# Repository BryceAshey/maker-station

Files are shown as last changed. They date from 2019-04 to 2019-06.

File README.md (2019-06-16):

# Maker Station
Powering your maker prototypes + some extra fun with HUE

Maker Station

## Setup

### Setup python and i2c on the pi
		sudo apt-get update
		
		sudo apt-get install python3 python3-pip git
		
		sudo pip3 install smbus2
		
		sudo apt-get install -y i2c-tools

### Setup hue
Install the phue lib

		sudo pip3 install phue

Set an environ var of HUE_BRIDGE_IP to the IP of your hue bridge

Set an environ var of HUE_BRIDGE_USERNAME to an authorized username from your Hue. 

To get a username from your hue: https://www.sitebase.be/generate-phillips-hue-api-token/

### Setup megaio
This will setup megaio from the command line and for use by python

		~$ git clone https://github.com/SequentMicrosystems/megaio-rpi.git
		
		~$ cd megaio-rpi/
		
		~/megaio-rpi$ sudo make install

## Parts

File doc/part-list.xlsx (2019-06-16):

Vendor | Part No. | Manufacturer | Description | Quantity | Cost Ea. | Cost Total
digikey.com | ECE60US05-S | XP Power | 10amp of 5v Power | 1 | $87.55 | $87.55
digikey.com | ECE60US12-S | XP Power | 10amp of 12v Power | 1 | $87.55 | $87.55
adafruit.com | 3055 | Raspberry Pi | Raspberry Pi 3 - Model B - ARMv8 with 1G RAM | 1 | $35.00 | $35.00
adafruit.com | 3708 | Raspberry Pi | Raspberry Pi Zero WH (Zero W with Headers) | 1 | $14.00 | $14.00
adafruit.com | 2883 | Raspberry Pi | Adafruit Pi Protector for Raspberry Pi Model Zero | 1 | $4.95 | $4.95
amazon.com | B014KTSMLA | Sunfounder | SunFounder PCA9685 16 Channel 12 Bit PWM Servo Driver for Arduino and Raspberry Pi | 1 | $10.19 | $10.19
robotshop.com | RB-SQM-02 | Sequent Microsystems | Mega-IO Expansion Card for Raspberry Pi/Zero | 1 | $35.00 | $35.00
sparkfun.com | bob-12700 | SparkFun | SparkFun USB Type A Female Breakout | 9 | $4.50 | $40.50
amazon.com | LA128A | Baomain | push button switch 16mm Momentary 1NO 1NC 3V White Neon Light rectangle 5 Pack | 3 | $7.19 | $21.57
sparkfun.com | COM-11310 | SparkFun | Toggle Switch and Cover - Illuminated (Red) | 2 | $2.95 | $5.90
adafruit.com | 3174 | adafruit | Hook-up Wire Spool Set - 22AWG Solid Core - 10 x 25ft | 1 | $29.95 | $29.95
grainger.com | 5ZDG7 | grainger | 100' 18ga red hookup wire (only need 30' ish) | 1 | $28.27 | $28.27
grainger.com | 5ZDG5 | grainger | 100' 18ga black hookup wire (only need 30' ish) | 1 | $28.27 | $28.27
dynamism.com | Ultimaker NFC PLA - Red | ultimaker | Ultimaker NFC PLA - Red Filament, .75kg, 2.85mm | 2 | $49.95 | $99.90
amazon.com | 260-004-BR | E-Z LOK | EZ Lok 260-004-BR, 4-40 Flanged Press Insert, Brass - Lot of 50 | 2 | $17.00 | $34.00
grainger.com | 4XB86 | FABORY | #4-40 x 1/4", Cylindrical, Socket Head Cap Screw, Alloy Steel, Steel, Black Oxide Finish, 100PK | 1 | $11.64 | $11.64
microfasteners.com | fwk04 | micro | #4 - Flat Washers - Black Oxide 100 pcs/pkg | 1 | $2.00 | $2.00
 |  |  | USB mount screws - unknown! | 8 |  | $0.00
 |  |  | USB mount screw nuts - unknown! | 24 |  | $0.00
 |  |  | Numerous JST Connectors
 |  |  | Total Cost at Build: |  |  | $576.24

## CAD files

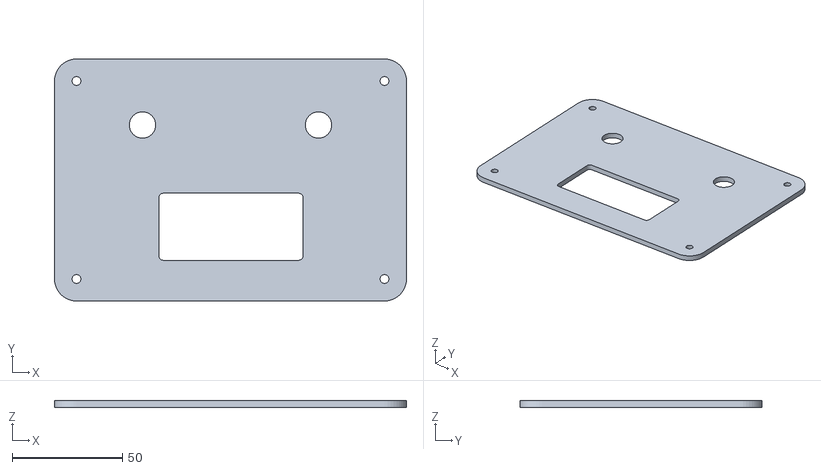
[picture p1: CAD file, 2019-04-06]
doc/stl/PowerBoxFacePlateWPiZero.stl
160.0 x 110.0 x 3.00

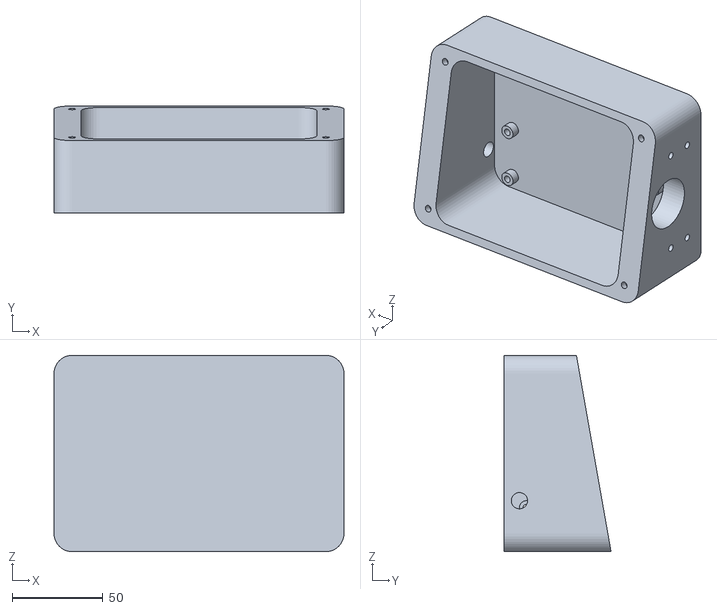
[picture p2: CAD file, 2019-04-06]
doc/stl/PowerBoxRight.stl
160.0 x 59.1 x 108.3

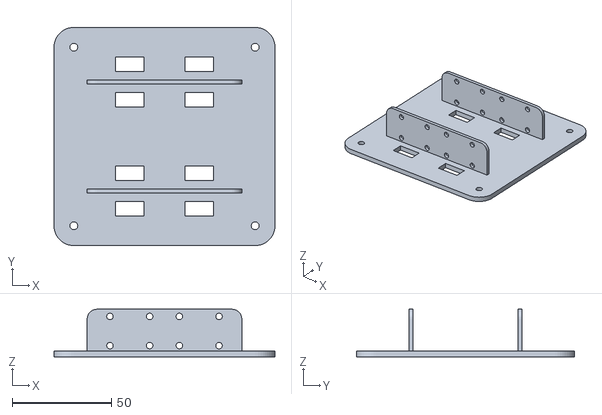
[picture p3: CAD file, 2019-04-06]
doc/stl/SmallBoxUsbPlate.stl
111.4 x 110.0 x 24.0

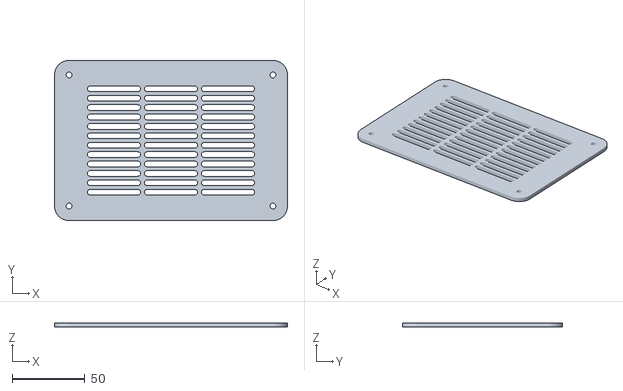
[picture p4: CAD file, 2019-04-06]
doc/stl/LargeBoxVentFaceplate.stl
160.0 x 110.0 x 3.00

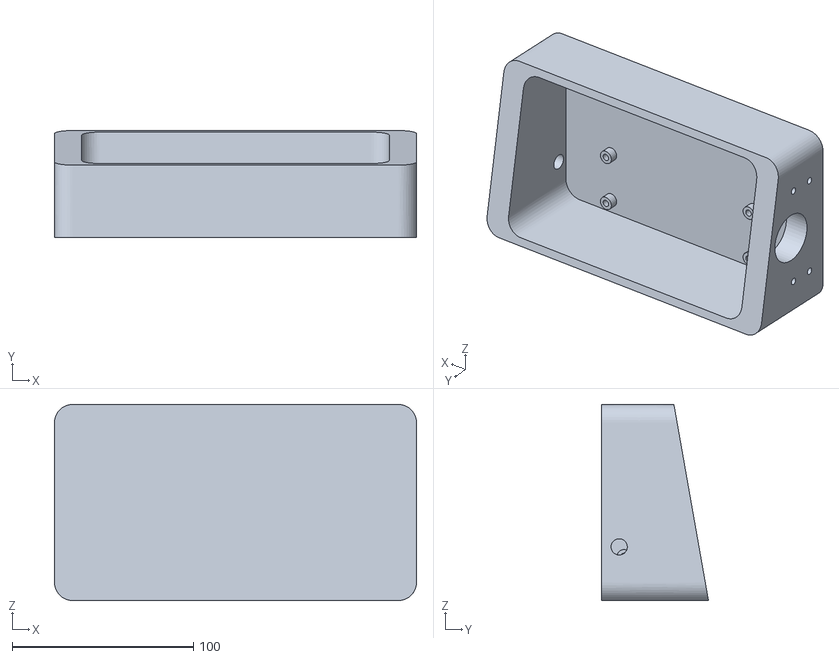
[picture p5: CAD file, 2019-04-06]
doc/stl/PowerBox.stl
200.0 x 59.1 x 108.3

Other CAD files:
doc/stl/ComputeBox.stl
doc/stl/Maker Station v39.f3d

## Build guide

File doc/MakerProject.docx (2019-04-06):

As makers we deal with the common problem of powering our creations while we’re prototyping them. For me, it’s not an uncommon occurrence to have a couple Raspberry Pi’s, an Arduino, and maybe a 7” touchscreen or two sitting on the workbench at any given point in time. When I originally came up with the concept for the Maker Station I was searching for a solution to that power problem and, ideally, I wanted a project that would force me to learn CAD, wiring with JST connectors, to develop a better understanding of the Raspberry’s GPIO and the I2C protocol, and whatever other geekery I could pile into the project. After a solid four weeks of development I can safely say Maker Station met all those desires and then some.

Specifications:

Power: 10 amps @5v via 8 USB

Switching capability: 15

Compute: Raspberry Pi Model 3b (although the 2 through 3b+ would work fine) – make sure you have Wi-Fi ability

PCA9685 I2C Controller (used for the switch LEDs not servos)

A spare Pi-Zero is installed on the power box faceplate but not currently used

Source code, part list, and general documentation:

https://github.com/BryceAshey/maker-station

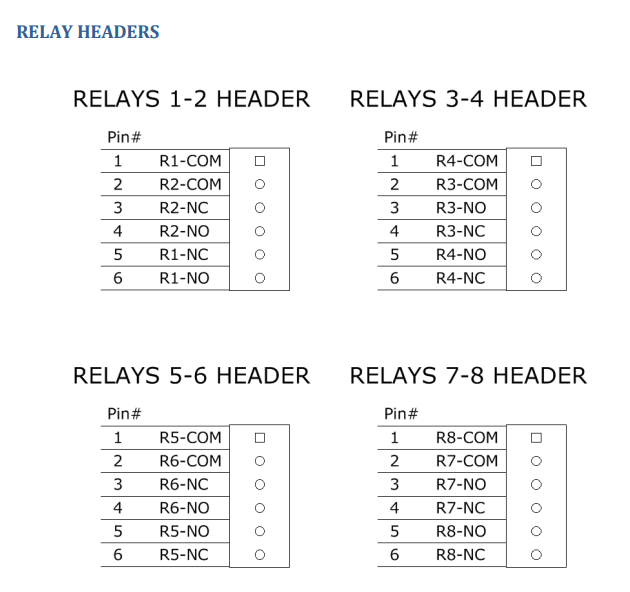
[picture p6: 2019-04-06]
doc/wiring/RelayHeaders.PNG

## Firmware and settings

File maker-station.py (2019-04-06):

#!/usr/bin/python3

# some of this script by Alex Eames https://raspi.tv  
# https://raspi.tv/how-to-use-interrupts-with-python-on-the-raspberry-pi-and-rpi-gpio-part-3  
import busio
import json
import megaio
import os
import RPi.GPIO as GPIO 
import signal

from adafruit_pca9685 import PCA9685
from array import *
from board import SCL, SDA
from phue import Bridge
from time import sleep

relay_state = [False, False, False, False, False, False, False, False, False]
spare_led = False

def flip_led(channel, flip):
    cycle = 0
    if(flip):
        cycle = 0x7fff
    pca.channels[channel].duty_cycle = cycle # https://learn.adafruit.com/16-channel-pwm-servo-driver/python-circuitpython

def switch_hue(channel):
    print('Switching HUE %s'%channel)
    # Switch LED will be handled by hue_check_state method
    b.set_group(channel, 'on', not b.get_group(channel, 'on'))

def switch_relay(channel, relay_num):
    print('Switching USB %s'%channel)
    relay_state[relay_num] = not relay_state[relay_num]
    if(relay_state[relay_num]):
        megaio.set_relay(0, relay_num, 1)
    else:
        megaio.set_relay(0, relay_num, 0)
    flip_led(channel, relay_state[relay_num])

def gpio_button_pressed(channel):  
    print('Rising edge detected on %s'%channel)
    global spare_led
    if(channel == 5): # Top Row
        switch_hue(1)
    elif(channel == 6):
        switch_relay(1, 1)
    elif(channel == 7):
        switch_relay(2, 2)
    elif(channel == 8): # Row 2
        switch_hue(2)
    elif(channel == 9):
        switch_relay(4, 3)
    elif(channel == 10):
        switch_relay(5, 4)
    elif(channel == 11): # Row 3
        switch_hue(3)
    elif(channel == 12):
        switch_relay(7, 5)
    elif(channel == 13):
        switch_relay(8, 6)
    elif(channel == 14): # Row 4
        switch_hue(4)
    elif(channel == 15):
        switch_relay(10, 7)
    elif(channel == 16):
        switch_relay(11, 8)
    elif(channel == 17): #Bottom Row
        switch_hue(5)
    elif(channel == 18):
        switch_hue(6)
    elif(channel == 19):
        print('Spare 0')
        spare_led = not spare_led
        flip_led(14, spare_led)
        
def hue_check_state():
    try:
        hue_all_rooms = b.get_group()
        for position in range(1, len(hue_all_rooms)+1):
            hue_room = b.get_group(position, 'on')
            if(position == 1):
                flip_led(0, hue_room)
            elif(position == 2):
                flip_led(3, hue_room)
            elif(position == 3):
                flip_led(6, hue_room)
            elif(position == 4):
                flip_led(9, hue_room)
            elif(position == 5):
                flip_led(12, hue_room)
            elif(position == 6):
                flip_led(13, hue_room)

    except Exception as e:
        print(e)
        
def setup_sigterm():
    signal.signal(signal.SIGTERM, shutdown_handler)
    signal.signal(signal.SIGINT, shutdown_handler)

def setup_gpio_button():
    GPIO.setmode(GPIO.BCM)
    i = 5
    while i <= 19:
        GPIO.setup(i, GPIO.IN, pull_up_down=GPIO.PUD_DOWN)
        GPIO.add_event_detect(i, GPIO.RISING, callback=gpio_button_pressed, bouncetime=300)  
        i += 1

def setup_pca():
    global i2c_bus 
    global pca
    i2c_bus = busio.I2C(SCL, SDA)
    pca = PCA9685(i2c_bus)
    pca.frequency = 60
        
def setup_hue():
    global b
    b = Bridge(os.environ['HUE_BRIDGE_IP'], os.environ['HUE_BRIDGE_USERNAME'])
    b.connect()
    
def init():
    setup_sigterm()
    setup_pca()
    setup_hue()
    setup_gpio_button()

def shutdown_handler(signum, frame):
    GPIO.cleanup()
    exit(0)

if __name__ == '__main__':
    try:
        init()

        # loop till the cows come home
        while True:
            hue_check_state()
            sleep(1)

    except KeyboardInterrupt:  
        GPIO.cleanup()       # clean up GPIO on CTRL+C exit  
    GPIO.cleanup()   

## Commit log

2019-04-06 added part-list
    [part-list.xlsx]
2019-04-06 updated part list
    [part-list.xlsx]
